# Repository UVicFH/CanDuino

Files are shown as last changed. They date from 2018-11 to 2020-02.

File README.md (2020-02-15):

# CanDuino
its a Can enabled Arduino, Can...Duino

Make sure to take The most recent version for projects.
Check The issues page for any know issues and if they have been fixed or not.

Onve the board has been made, follow these instructions to program

If you only partily follow these along with other internet suggestions then I don't care if you fail or break the board.
Follow these fully and nothing else. If it still doesn't work, THEN go use the internet.

1) BOOTLOADING

  a) get another arduino board
  
  b) upload the blink sketch to it (VERY IMPORTANT TO DO THIS AND CONFIRM YOU FOUND A WORKING BOARD)
  
  c) upload the ArduinoISP sketch to your now working arduino
  
  d) disconnect all boards from the computer
  
  e) conect wires as follows (Orginal Arduino -> New Canduino):
  
      5V -> 5V
      
      GND -> GND
      
      SCK (Pin 13) -> SCK
      
      MISO (Pin 12) -> MISO
      
      MOSI (Pin 11) -> MOSI
      
      Pin10 -> RESET  

  f) make sure the settings in the IDE are:
  
      Board: Arduino/Genuino UNO
      
      Port: The one it connects to
      
      Programmer: "Arduino as ISP"

  g) connect the Working Arduino (that is now coneected to the new Canduino) to the computer
  
  h) click burn bootloader (may need to change heartbeat to 20 from 40)
  
  i) when done disconnect the USB and all wires between the boards
  
2) UPLOADING CODE

  a) conect the new bootloaded Canduino to the computer via USB
  
  b) open your sketch
  
  c) change the board to "Arduino Pro or Pro Mini"
  
      Select "ATmega 328P (5V, 16 MHZ)" as the Processor, but uno seems to also work now???
      
  d) upload CAN test code - example sketch CAN receive_check and/ or CAN send_check to ensure CAN functionality
  
  e) upload your sketch
   
  e) enjoy

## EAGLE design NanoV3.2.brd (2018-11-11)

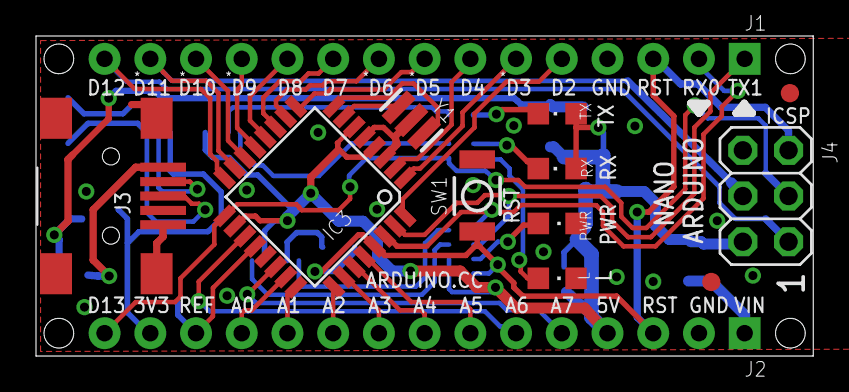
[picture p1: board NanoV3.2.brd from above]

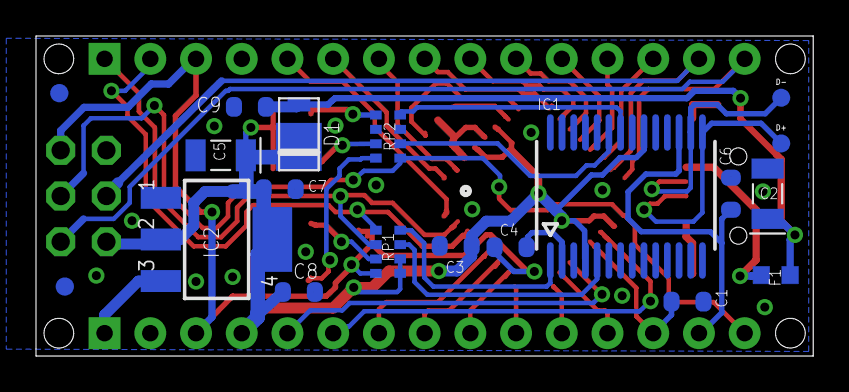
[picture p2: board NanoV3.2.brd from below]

Board: 2 copper layers, 43.2 x 17.8 mm, 33 parts (17 on the bottom side), 43 nets.

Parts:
C1, C4, C6, C9: 100nF; C0603-ROUND
C2, C5: 4,7uF_16V; TAN-A
C3, C7, C8: 1uF; C0603-ROUND
D1: SS1P3L; DO220AAL
D+: DNP; TP-1.00MM
D-: DNP; TP-1.00MM
F1: MFFSMF050; 0603-1608X90N
FRAME1: DNP; FRAME
IC1: FT232RL; SSOP28
IC2: LM1117IMPX-5.0; LINEAR_SOT223
IC3: ATMEGA328P-AU; TQFP32-08
J1, J2: XXXX_STRIPNANO; HEAD15-NOSS
J3: USB-MINI-B_2
J4: 2X03
L: Yellow; CHIPLED_0805
PWR: Green; CHIPLED_0805
RP1, RP2: 1K; CAY16
RX: Red; CHIPLED_0805
SW1: RESET; SMD_157SW
TX: Green; CHIPLED_0805
U$4, U$5, U$53, U$54: DNP; FD-1-1.5
Y1: 16MHz; RESONATOR

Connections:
3V3: C6.2, IC1.17, J2.14
+5V: C3.1, C5.1, C7.1, C8.1, D1.P$1, IC1.4, IC1.20, IC2.2, IC2.4, IC3.4, IC3.6, IC3.18, J2.4, J4.2, RP1.5, RP1.6, RX.A, TX.A
A0: IC3.23, J2.12
A1: IC3.24, J2.11
A2: IC3.25, J2.10
A3: IC3.26, J2.9
A4: IC3.27, J2.8
A5: IC3.28, J2.7
A6: IC3.19, J2.6
A7: IC3.22, J2.5
AREF: C1.1, IC3.20, J2.13
COM: C1.2, C2.2, C3.2, C5.2, C6.1, C7.2, C8.2, C9.2, IC1.7, IC1.18, IC1.21, IC1.25, IC1.26, IC2.1, IC3.3, IC3.5, IC3.21, J1.4, J2.2, J3.1, J3.6, J3.7, J3.8, J3.9, J4.6, L.C, PWR.C, RP2.3, RP2.6, SW1.1, Y1.2
D0/RX: IC3.30, J1.2, RP1.1
D1/TX: IC3.31, J1.1, RP1.2
D2: IC3.32, J1.5
D3: IC3.1, J1.6
D4: IC3.2, J1.7
D5: IC3.9, J1.8
D6: IC3.10, J1.9
D7: IC3.11, J1.10
D8: IC3.12, J1.11
D9: IC3.13, J1.12
D10: IC3.14, J1.13
D11/MOSI: IC3.15, J1.14, J4.4
D12/MISO: IC3.16, J1.15, J4.1
D13/SCK: IC3.17, J2.15, J4.3, RP2.1
unnamed: IC3.8, Y1.3
unnamed: IC3.7, Y1.1
unnamed: PWR.A, RP1.3
unnamed: C4.2, IC1.2
unnamed: D+.X, IC1.15, J3.3
unnamed: D-.X, IC1.16, J3.4
unnamed: L.A, RP2.8
unnamed: IC1.23, RP2.2
unnamed: IC1.22, RP2.4
unnamed: RP2.5, TX.C
unnamed: F1.2, J3.5
unnamed: RP2.7, RX.C
RESET: C4.1, IC3.29, J1.3, J2.3, J4.5, RP1.4, SW1.2
RX: IC1.1, RP1.8
TX: IC1.5, RP1.7
VIN: IC2.3, J2.1
VUSB: C2.1, C9.1, D1.P$2, F1.1

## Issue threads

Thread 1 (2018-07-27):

V1 print issues

akshdeepmaan, 2018-07-27:
The D4 diode for USB protection was backwards. (fixed in v2018_7_27)
The TX RX header should be directly connected to the at-mega chip and not through the 1K resistors (fixed in v2018_7_27)

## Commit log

2018-07-08 New Canduino
    A arduino 328p
    A can shield module
    A USB interface
    A circle PCB
    What more could anyone want...
    [Atmel Footprints.PcbLib, Candunio v2018july.PrjPcb, Candunio.PcbDoc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]
2018-07-11 Add files via upload
    Updated after design review 1
    Debugging leds added
    Part numbers now mostly match digikey components
    Silk screen is more useful
    more output pins
    slight board rearrangment
    [Atmel Footprints.PcbLib, Candunio v2018_7_11.PrjPcb, Candunio.PcbDoc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]
2018-07-12 Add files via upload
    The part numbers should be good for real this time.
    [Candunio v2018_7_11 BOM.xlsx, Candunio v2018_7_11.PrjPcb, Candunio.PcbDoc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]
2018-07-15 Add files via upload
    Even more changes
    [Atmel Footprints.PcbLib, Candunio v2018_7_11 BOM.xlsx, Candunio v2018_7_11.PrjPcb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]
2018-07-16 V1 finalized for print
    Design review 2 complete
    Mounting holes added,
    Rules checks,
    Nets fixed.
    [Atmel Footprints.PcbLib, Candunio v2018_7_11 BOM.xlsx, Candunio v2018_7_11.PrjPcb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]
2018-07-16 Add files via upload
    Hopefully finally ready for V1 print
    2 full design reviews done and updated
    TX/RX on USB chip where backward
    Input 12V decoupling cap added
    Vias aligned for OCD reasons
    [Candunio v2018_7_15.PrjPcb, Candunio.PcbDoc, Candunio.SchDoc]
2018-07-16 Add files via upload
    Changed part numbers to reduce cost
    [Candunio v2018_7_15.PrjPcb, Candunio v2018_7_15.csv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]
2018-07-17 Add files via upload
    Fixed footprints
    Added 3d models
    [Candunio v2018_7_17.PrjPcb, Candunio.PcbDoc, Candunio.SchDoc]
2018-07-21 Add files via upload
    Edited and sent for V1 PCB print.
    Pad size changed to account for black solder mask min width
    Gerber files fixed for printing.
    As long as the PCB is correct when assembled this file can be used for further projects
    Check on updates if anything changes.
    [Candunio v2018_7_17.PrjPcb, Candunio v2018_7_17.xlsx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]
2018-07-28 Add files via upload
    This is ready for V2 Print
    Refer to Issues page on V1 print errors for a list of everything changed.
    My bad....
    [Candunio v2018_7_27.PrjPcb, Candunio.PcbDoc, Candunio.SchDoc]
2018-08-07 Add files via upload
    made library changes to consolidate capacitors and make SMD switch look better
    [Candunio v2018_8_7.PrjPcb, Candunio.PcbDoc, Candunio.SchDoc]
2018-09-15 Add files via upload
    checked pcb and schematic for footprints. Should be good to go for V2 print.
    USB working well, with USB diode footprint correct.
    No input power protection or ports in this design. be sure to add as required.
    [Candunio v2018_8_8.PrjPcb, Candunio.PcbDoc, Candunio.SchDoc]
2018-11-11 Version 2
    1) folder structure changed to better use github.
    2) library updated to use only ingergrated library files
    3) PCB re made to be smaller and more usable rectangular size
    4) Arduino micro/nano pinout used to made intergration into new designs easier
    [Atmel Footprints.PcbLib, Candunio v2018_7_11 BOM.xlsx, Candunio v2018_7_11.PrjPcb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]
2018-11-11 v2.1
    added more ground plane stiching
    added teardroping on pins
    added USB grounding via connector
    [Candunio.PcbDoc, Candunio.SchDoc]
2018-11-14 V2.2
    Now with almost no errors!
    fixed min hole size on the pcb so it can be made for cheap.
    [Candunio.PcbDoc, Candunio.PrjPcb]
2020-01-18 Version 2.3
    Added reverse diode on 12V input from car
    Added pin headers to fix hole spaing and allow board to slot into proto boards
    Still to do: Check header to header ( board width) to make standard
    [Candunio.PrjPcb, Candunio.SchDoc]
2020-02-15 Version 2.4 almost print ready
    changed 12V protection connection
    fixed diode silkscreens and 3d models
    made headers standard 2.54mm spacing
    cleaned up rules checks
    made a step file output
    [1206SMDswitch.PcbLib, Candunio.PcbLib, Candunio.PrjPcb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]
2020-07-27 Version 2.5 Added Can to pin headers (Ready to print?)
    added CanL and CanH to edge headers and moved GND pin. Reflowed grounds. Should be ready to print.
2020-08-25 Silkscreen and schematic header update
    Added the silkscreen for the header pins. Updated the schematic headers J2 and J3 to reflect CAN changes Aksh made.
2020-08-26 I dont know if the last push worked?
    [Candunio.SchDoc]
2020-08-27 Flipped header silkscreen
    put header label silkscreen on top because I accidentally put it on the bottom last time. :(
2020-09-02 FOUND PROBLEMS, HALP
    fuze in wrong location, need to change
    [Candunio.GBL, Candunio.GBO, Candunio.GBP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]
2020-09-03 V2.6 +5V_F routing
    fixed the pcb routing to resolve the fuse issue found in a previous push.
    [Candunio.PcbDoc]
2020-09-04 V2.7 misssed some routing
    [Candunio.PcbDoc]
2020-09-07 V2.8 Simplified +5V_F trace
    [Candunio.PcbDoc, Candunio.PrjPcb]
2020-09-07 V2.8 Apparently it didn't update last push?
    [Candunio.PcbDoc]
2020-09-07 V2.85 Minor fixes
    Diode checks
    Trace witdhs made same and thicker
    silk screen for fuze made same size
    silk screen orientation fized to lineup
    [Candunio.PcbDoc]
2020-09-10 V2.9 traces fixed and gerbers made
    alignment issues and minor traces fixes
    [Candunio.GBL, Candunio.GBO, Candunio.GBP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]

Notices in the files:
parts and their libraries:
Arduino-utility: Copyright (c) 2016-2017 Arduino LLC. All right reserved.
